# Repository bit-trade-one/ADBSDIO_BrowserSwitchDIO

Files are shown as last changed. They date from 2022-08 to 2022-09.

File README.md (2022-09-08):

# ADBSDIO/ADBSDIOMB_BrowserSwitchDIO
## 本体画像
<br>
<br>

WEBブラウザから接点監視・制御が可能なブラウザスイッチDIOのリポジトリです。

## [HPリンク](https://bit-trade-one.co.jp/adbsdio/) 

## [サポートサイト](https://bit-trade-one.github.io/ADBSDIO_BrowserSwitchDIO/)

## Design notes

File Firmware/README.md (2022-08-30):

# filelist
- Browser_Switch_DIO_Ver.XX.ino  
ファームウェア(Arduinoスケッチ)です。  
  
- Browser_Switch_DIO_Ver.XX.ino.leonardo.hex  
hexファイルです。 こちらはUSBVID・PIDが弊社で割り当てたものになっています。

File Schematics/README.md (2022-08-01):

# filelist
- ADBSDIO_PCBV0.pdf  
ADBSDIOの基板図です。
  
- ADBSDIO_SchematicV0.pdf  
ADBSDIOの回路図です。

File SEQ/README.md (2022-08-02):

※GitHubの使い方は[こちら](https://bit-trade-one.co.jp/h2gh/)の記事をご確認ください。
# filelist

- ADBSDIO_SEQ.pdf  
ADBSDIOの展開接続図のPDF版です。  
  
- ADBSDIO_SEQ.zip  
ADBSDIOの展開接続図のdxf版です。  
解凍してご利用ください。  
  
- 改造例SEQ.pdf  
既設盤と上記の配布SEQを組み合わせた展開接続図改造のサンプルです。

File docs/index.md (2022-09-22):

BTO-logo (https://bit-trade-one.co.jp/)

<a href="https://twitter.com/share?ref_src=twsrc%5Etfw" class="twitter-share-button" data-hashtags="Arduino,ブラウザスイッチDIO,BitTradeOne,ビット・トレード・ワン" data-url="https://bit-trade-one.github.io/ADBSDIO_BrowserSwitchDIO/" data-via="BitTradeOne" data-text="ブラウザスイッチDIOサポート" data-show-count="false">Tweetする</a>
<script async src="https://platform.twitter.com/widgets.js" charset="utf-8"></script>
       
# 出荷時設定
[IPaddress：192.168.1.10](http://192.168.1.10/)  
IPAddress subnet：255.255.255.0  
IPAddress gateway：192.168.1.1  
IPAddress dnsServer：192.168.1.1  

MACaddress：本体基板にシールで添付  
(汎用ターミナルソフトからも確認可能)  

コチラは変更可能です。  
下記のドキュメント項をご確認ください。  
  
ADBSDIOとADBSDIOMBの基板は同一のものです。  
# リンク
[製品HP](https://bit-trade-one.co.jp/adbsdio/)
# ドキュメント
<details><summary><strong>ADBSDIO概要</strong> </summary>
ADBSDIOと同ネットワークの端末WEBブラウザからリレー接点のON・OFFと接点がHIGHかLOWかの監視が可能です。<br>
またターミナル経由等でMACAddressと接続に使うIPAddress等の変更が可能です。<br>
入出力接点は全点絶縁されています。<br>
入出力接点端子はM3のネジ端子とピンソケットを用意しています。お好きな方をご利用ください。<br>
</details><br>
       
<details><summary><strong>簡易使用方法</strong> </summary>
1.ADBSDIOにUSBかネジ端子から電力を供給します。ネジ端子は8~26Vの電源の入力が可能です。+-に注意して接続してください。<br><br>
2.LANケーブルを接続しADBSDIOをネットワークに接続してください。<br>
制御端末もADBSDIOと同じネットワークに接続してください。<br><br>
<br>
<a href="https://user-images.githubusercontent.com/85532743/185073396-862e1109-ad1b-4813-9fc3-05c2a0810da8.png">クリックで拡大</a><br><br>
       
3.端末のブラウザから<a href="http://192.168.1.10/">http://192.168.1.10/</a>  に接続します。ここから監視・制御が可能です。<br>
 <br>
4.ネジ端子、ピンソケットに入力するもの、制御するものを接続ください。<br>
ネジ端子とピンソケットは赤枠で囲んだ部分が導通しています。<br>
<br><br>
<a href="https://user-images.githubusercontent.com/85532743/185340369-3af2de3d-b216-49eb-99b5-b47f519a5fbc.png">クリックで拡大</a><br><br>
<br>
<a href="https://user-images.githubusercontent.com/85532743/185077119-d89ff999-6a3d-499f-8601-80c3894757f6.png">クリックで拡大</a><br><br>
電圧入力はINの側が入力OUTの側が出力になるように接続ください。<br>
ブラウザスイッチは絶縁入力のため、入力部を駆動できる電圧が必要です。<br>
ブラウザスイッチ本体の5V出力を使うか、外部に電源を持たせて信号入力を行ってください。(DCIN 5~24V)<br>
無電圧接点出力(リレー接点出力)はCOMのC接点,NOのA接点,NCのB接点に気をつけて接続ください。(AC125V/3A, DC30V/3A)<br>
※ノイズの大きな機器をリレー接点に接続する場合は対策を行ってください。本体の動作に影響が出る可能性があります。<br>
また、比較的高い電圧を使う場合は細心の注意をはらってご使用ください。<br>
ADBSDIOのネジ端子に対応する裸端子は丸形 ニチフR0.75-3.5などです。<br>
</details><br>

<details><summary><strong>URLパラメータでの制御方法</strong> </summary>
ブラウザスイッチではURLのパラメータを確認して出力を制御しているため、以下のURLを送ることでも制御可能です。<br><br>
DO0のON<br>
http://192.168.1.10/?DO0=ON<br>
DO0のOFF<br>
http://192.168.1.10/?DO0=OFF<br>
DO1のON<br>
http://192.168.1.10/?DO1=ON<br>
DO1のOFF<br>
http://192.168.1.10/?DO1=OFF<br>
       
尚、IPアドレスを変更した場合は適宜読み替えてください。<br><br>

</details><br>

<details><summary><strong>MACAddress書き換え方法</strong> </summary>
1.ADBSDIOと設定するPCをUSBケーブルで接続してください。<br><br>
2.PC画面左下Windowsマークを右クリックし、デバイスマネージャを選び、ADBSDIOのCOMポート番号を確認してください。<br>
<br><br>
3.PCでTeraTermなどターミナルソフトを開き、COMポートを選択します。<br>
<br><br>
4.TeraTermの場合上のメニューから設定>端末を選び、送信の改行はLFを設定してください。<br>
<br>
<br><br>
5.なにかボタンを押すとセッティングモードに入ります。<br>
セッティングモードに入ったら「1」と「Enter」を入力してください。<br>
 注意:入力された文字はEnterを押すまでPC画面に反映されません。<br>
<br><br>
6.NEW_MAC_Address？と聞いてくるので新しいMACAddressを英数字のみで入力してください。<br>
大文字小文字は関係なく大文字に変換されます。<br>
入力に失敗しエラーが出た場合は5秒待ち、キーを入力し設定モードに入るところからやり直してください。<br>
設定ができたらUSBケーブルを抜き差しするかリセットボタンを押して再起動してください。MACAddressが適応されます。<br>
<br>
</details><br>

<details><summary><strong>MACAddress以外書き換え方法</strong> </summary>
1.ADBSDIOと設定するPCをUSBケーブルで接続してください。<br><br>
2.PC画面左下Windowsマークを右クリックし、デバイスマネージャを選び、ADBSDIOのCOMポート番号を確認してください。<br>
<br><br>
3.PCでTeraTermなどターミナルソフトを開き、COMポートを選択します。<br>
<br><br>
4.TeraTermの場合上のメニューから設定>端末を選び、送信の改行はLFを設定してください。<br>
<br>
<br><br>
5.なにかボタンを押すとセッティングモードに入ります。<br>
セッティングモードに入ったら「設定したい数字」と「Enter」を入力してください。<br>
今回は例としてIPAddressを設定します。「2」と「Enter」を入力してください。<br>
注意:入力された文字はEnterを押すまでPC画面に反映されません。<br>    
<br><br>
6.NEW_IP_Address？と聞いてくるので新しいIPAddressを数字のみで入力してください。<br>
入力に失敗しエラーが出た場合は5秒待ち、キーを入力し設定モードに入るところからやり直してください。<br>
設定ができたらUSBケーブルを抜き差しするかリセットボタンを押して再起動してください。MACAddressが適応されます。<br>
<br>

</details><br>

<details><summary><strong>ランド説明</strong> </summary>
ADBSDIOにはユーザがパターンカットやハンダブリッジをして設定ができるパッドが4つあります。<br>
恐れ入りますがハンダブリッジ・パターンカットをした場合保証は外れます。<br>
<br>
<a href="https://user-images.githubusercontent.com/85532743/182118702-53898fa7-c564-4b55-8915-5920560c63e0.png">クリックで拡大</a><br><br>

パターンカットはランドが露出していない部分をカッターナイフで2ラインほど切ると良いです。<br>
オープンしているパターンはランドをハンダブリッジで接続すると回路が閉じます。<br>
<br>

1.DI入力かAI入力か<br>
デフォルトでは絶縁のDI入力が選ばれていますが、パターンカットしてAIをハンダブリッジすることにより<br>
非絶縁AI入力が可能になります。なお、お客様の方でファームウェアを修正・書き直していただく必要があります。<br>
詳しくは回路図・ファームウェアをご確認ください。<br><br>

2.カットでブリーダ抵抗無効<br>
パターンをカットすることにより、ブリーダ抵抗が無効になり、入力側に流れる電流が減ります。<br>
詳しくは回路図をご確認ください。<br>
ブリーダ抵抗が無効の場合<br>
DC5Vを入力すると5mA，DC24Vを入力すると24mA電流が流れます。<br>
ブリーダ抵抗とは電流を多く流すために回路に並列に接続された抵抗です。<br>
接続する機器の接点定格の最小適用負荷に応じて、流れる電流を調整するために挿入されます。<br>
ブリーダ抵抗が有効の場合<br>
DC5Vを入力すると12.5mA，DC24Vを入力すると60mA電流が流れます。<br>
<br>
接続する接点に合わせて設定ください。<br><br>
<br>
<a href="https://user-images.githubusercontent.com/85532743/185068188-b91116f9-3ff9-4cda-ad21-cb990ff6aed6.png">クリックで拡大</a><br><br>
<br>
機器の接点が劣化し酸化膜が生成され小信号が伝達できなくなることを防ぐために<br>
接点部にメッキなどを施した製品は微小負荷接点対策品などと呼ばれます。<br>
<br>
接点に施しが無い、微小負荷接点対策がされていない機器は要求する最小負荷が大きく、<br>
接点に対してある程度大きな電流を流す必要があります。<br>
<br>
例えば富士電機製スーパータイマ MS4Sシリーズは、<br>
接点の最小適用負荷が DC5V10mAとなっています。<br>
この接点にはDC5V10mA以上の電圧・電流を流さないと、タイマ接点に発生する酸化皮膜などの絶縁が破壊できず、<br>
タイマ接点を閉じても電気信号が伝わらない可能性があります。<br>
<br>
ブリーダ抵抗を有効にすると、5Vの電源の場合約12mAを流すことが出来るので、<br>
タイマ接点からの信号を問題なく受け取ることが出来ます。  <br>
<br><br>
3.ブリッジでVIN端子有効<br>
ここをハンダブリッジすると、VIN端子より電源供給が可能になります。
詳しくは回路図をご確認ください。<br><br>
       
4.W5500設定<br>
ここをハンダブリッジすると、W5500の設定を変更することが出来ます。
詳しくは回路図・Wiznet社W5500のHPをご確認ください。<br><br>
</details><br>

<details><summary><strong>ファームウェア書き込み方法</strong> </summary>
       
ファームウェアはハードウェアの中に書き込まれているソフトウェアです。<br>
不具合修正や機能追加された新しいファームウェアが公開された際、<br>
ファームウェアをアップデートすることで新しい機能が使用できます。<br>
       
ADBSDIOはArduinoLeonardo互換のため、ArduinoIDEよりArduinoLeonardoを選択肢してUSBケーブル経由で<br>
ファームウェアを書き込む事ができます。<br>
なお、ArduinoIDEより書き込んだ場合ビット・トレード・ワンで付与したUSBVID・PIDではなくなります。<br>
通常使用では問題ありませんが、ADBSDIOを別の製品として再販売する場合はArduino社・弊社のUSBVID・PIDで販売することは<br>
推奨されていませんのでご注意ください。<br>
</details><br>

<details><summary><strong>DINレールについて</strong> </summary>
       
ケース付きのADBSDIOはDINレールに取り付けることが可能です。<br>
取り外しの際は白いレバーを引きながら取り外してください。<br>
</details><br>
  
# サポートファイル等
- [回路図・基板図](https://github.com/bit-trade-one/ADBSDIO_BrowserSwitchDIO/tree/master/Schematics)
- [配布展開接続図・改造例展開接続図サンプル](https://github.com/bit-trade-one/ADBSDIO_BrowserSwitchDIO/tree/master/SEQ)
- [ファームウェア・HEX](https://github.com/bit-trade-one/ADBSDIO_BrowserSwitchDIO/tree/master/Firmware) 
- [Q&A](FAQ.md)

# スペシャルサンクス
参考にさせていただきました。  
心より感謝いたします。誠にありがとうございました。

- [W5500](https://www.wiznet.io/product-item/w5500/)
- [Ethernet Library for Arduino](https://github.com/arduino-libraries/Ethernet)  
- Starting Electronics [Analog Inputs and Switches using AJAX](https://startingelectronics.org/tutorials/arduino/ethernet-shield-web-server-tutorial/AJAX-read-switches-analog/)  
- The Strange Storage [Arduino Ethernet シールド [改訂増分版]](https://www.storange.jp/2014/04/arduino-ethernet.html)

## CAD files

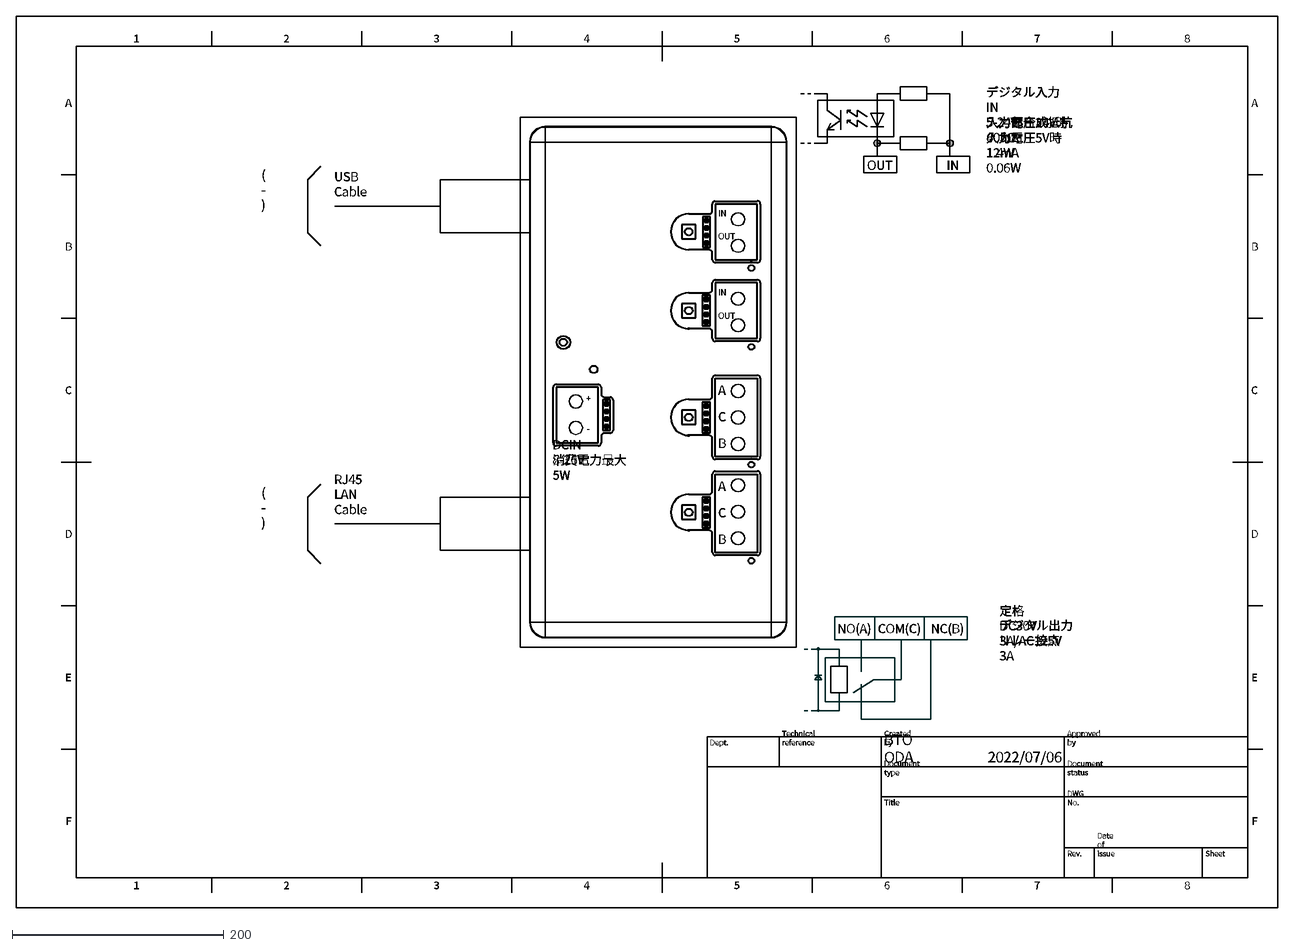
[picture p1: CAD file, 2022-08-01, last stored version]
SEQ/ADBSDIO_SEQ.dxf
1
A
2
3
4
5
6
7
8
B
C
D
E
F
Dept.
Technical reference
Created by
Approved by
Document type
Document status
Title
DWG No.
Rev.
Date of issue
Sheet
2022/07/06
BTO ODA
USB Cable
RJ45 LAN Cable
( - )
デジタル入力 IN 5-24V
入力部合成抵抗 405Ω
入力電圧24V時 60mA 1.4W
入力電圧5V時 12mA 0.06W
OUT
IN
デジタル出力
リレー接点
定格 DC30V 3A/AC125V 3A
NO(A)
COM(C)
NC(B)
DCIN 8-26V
消費電力最大 5W
+
-

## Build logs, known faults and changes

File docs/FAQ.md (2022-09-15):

# ADBSDIO_BrowserSwitchDIO よくある質問

---
## Q.入力部と制御回路は絶縁されていますか？

### A.はい 絶縁されています
絶縁耐圧等の公開はしておりません。

---

## Q.インジケータランプ・テスト用接点スイッチは入力部と絶縁されていますか。

### A.はい 絶縁されています

詳しくは[回路図](https://github.com/bit-trade-one/ADBSDIO_BrowserSwitchDIO/blob/master/Schematics/ADBSDIO_SchematicV0.pdf)をご確認ください。  

---

## Q.赤いランプが点滅して設定サイトにつなげません。故障ですか？

### A.MACアドレスが書き込まれていないという意です

何らかの原因でMACアドレスが保存されていない可能性がございます。  
サポートサイトを参考にMACアドレスを設定ください。  

---

## Q.設定サイトに繋がりません

### A.下記をご確認ください

- 本体に電源は刺さっているか
- LANケーブルは刺さっているか
- ネットワークに接続されているか
- 設定サイトにつなぐ端末が本体と同じネットワークに居るか  

上記で解消されない場合、別のIPアドレスにすると直ることがあります。 
(同じIPAddressを使用した機器がネットワーク内にいる場合に発生します。)  
サポートトップドキュメントのIPAddress書き換え方法をご覧ください。  
  
それでも解消されない際は[お問い合わせ](https://bit-trade-one.co.jp/contactus/)ください。  

---

## Q.設定サイトには同時に何台まで接続できますか？

### A.2,3台接続できることは確認しています。

弊社環境での確認です。

それぞれの端末が非同期で値を確認するため、常時多数接続には向いていないかもしれません。

---

## Q.DHCPに対応していますか？

### A.非対応です。

発売時FWでは対応していませんが、  
W5500を採用しているため、FWをお客様の方で作成していただければDHCP対応は可能です。

しかし本体メモリの消費が大きいため実装時はご注意ください。

---

## Q.IPv6に対応していますか？

### A.非対応です

W5500を採用しているため、IPv4にのみ対応しています。  

---
## Q.電源を消した場合DO出力のHIGH・LOWは保持されますか？

### A.保持されません

DO出力のHIGH・LOWは揮発メモリ上で管理されているため、電源を抜くと初期値の双方LOWに戻ります。  
電源が不安定な状況などでのご使用にはご注意ください。  

---

## Q.USB電源とねじ端子からの電源を双方つなぎ、電源の二重化をすることは可能ですか？

### A.そのような使い方は想定しておりません。

逆流防止ダイオードが実装されているので双方繋いでも故障等は発生しませんが、  
電源の二重化として使用する事は想定しておりません。  

---

## Q.確認用LEDが光っているけど信号入力されません

### A.入力電圧が低い可能性がございます。

LEDの特性により、入力に値しない低めの電圧が入力されたときでも確認用LEDが光ることがございます。  
5V以上の信号を入力ください。

---

## Q.ブラウザではなくコマンドラインから制御することは可能ですか？

### A.あくまで簡易的ですが、可能です。

wgetコマンドを使用することによりDO出力のON・OFFを行うことができます。  
連続実行した場合は、直前のコマンドが無視されるなど不安定な挙動をすることがあります。  
また、タイムアウトとトライ回数については、用途に応じて調整する必要があります。  

Linuxの場合  
```
wget -T 5 -t 1 -O /dev/null http://192.168.1.32/DO0=ON  2> /dev/null #DO0 ON
wget -T 5 -t 1 -O /dev/null http://192.168.1.32/DO0=OFF 2> /dev/null #DO0 OFF
wget -T 5 -t 1 -O /dev/null http://192.168.1.32/DO1=ON  2> /dev/null #DO1 ON
wget -T 5 -t 1 -O /dev/null http://192.168.1.32/DO1=OFF 2> /dev/null #DO1 OFF
```
 
Windowsの場合（wgetコマンドは別途インストールする必要があります）  
```
wget -T 5 -t 1 -O nul http://192.168.1.32/DO0=ON  2> nul ; DO0 ON
wget -T 5 -t 1 -O nul http://192.168.1.32/DO0=OFF 2> nul ; DO0 OFF
wget -T 5 -t 1 -O nul http://192.168.1.32/DO1=ON  2> nul ; DO1 ON
wget -T 5 -t 1 -O nul http://192.168.1.32/DO1=OFF 2> nul ; DO1 OFF
```

---

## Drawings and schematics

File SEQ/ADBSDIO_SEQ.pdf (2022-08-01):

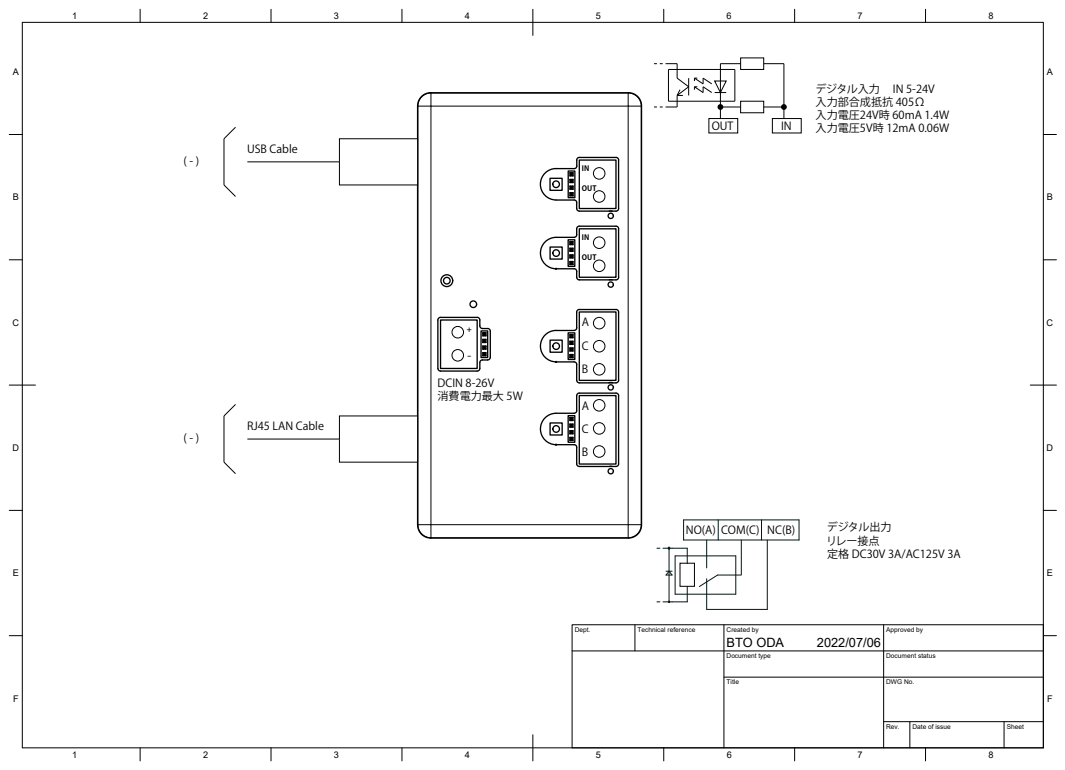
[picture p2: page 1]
Dept.; Technical reference; Created by; Approved by; Document type; Document status; Title; DWG No.; Rev.; Date of issue; Sheet; BTO ODA; USB Cable; RJ45 LAN Cable; デジタル入力 IN 5-24V 入力部合成抵抗 405Ω 入力電圧24V時 60mA 1.4W; OUT; 入力電圧5V時 12mA 0.06W; デジタル出力 リレー接点 定格 DC30V 3A/AC125V 3A; NO(A) COM(C); DCIN 8-26V 消費電力最大 5W

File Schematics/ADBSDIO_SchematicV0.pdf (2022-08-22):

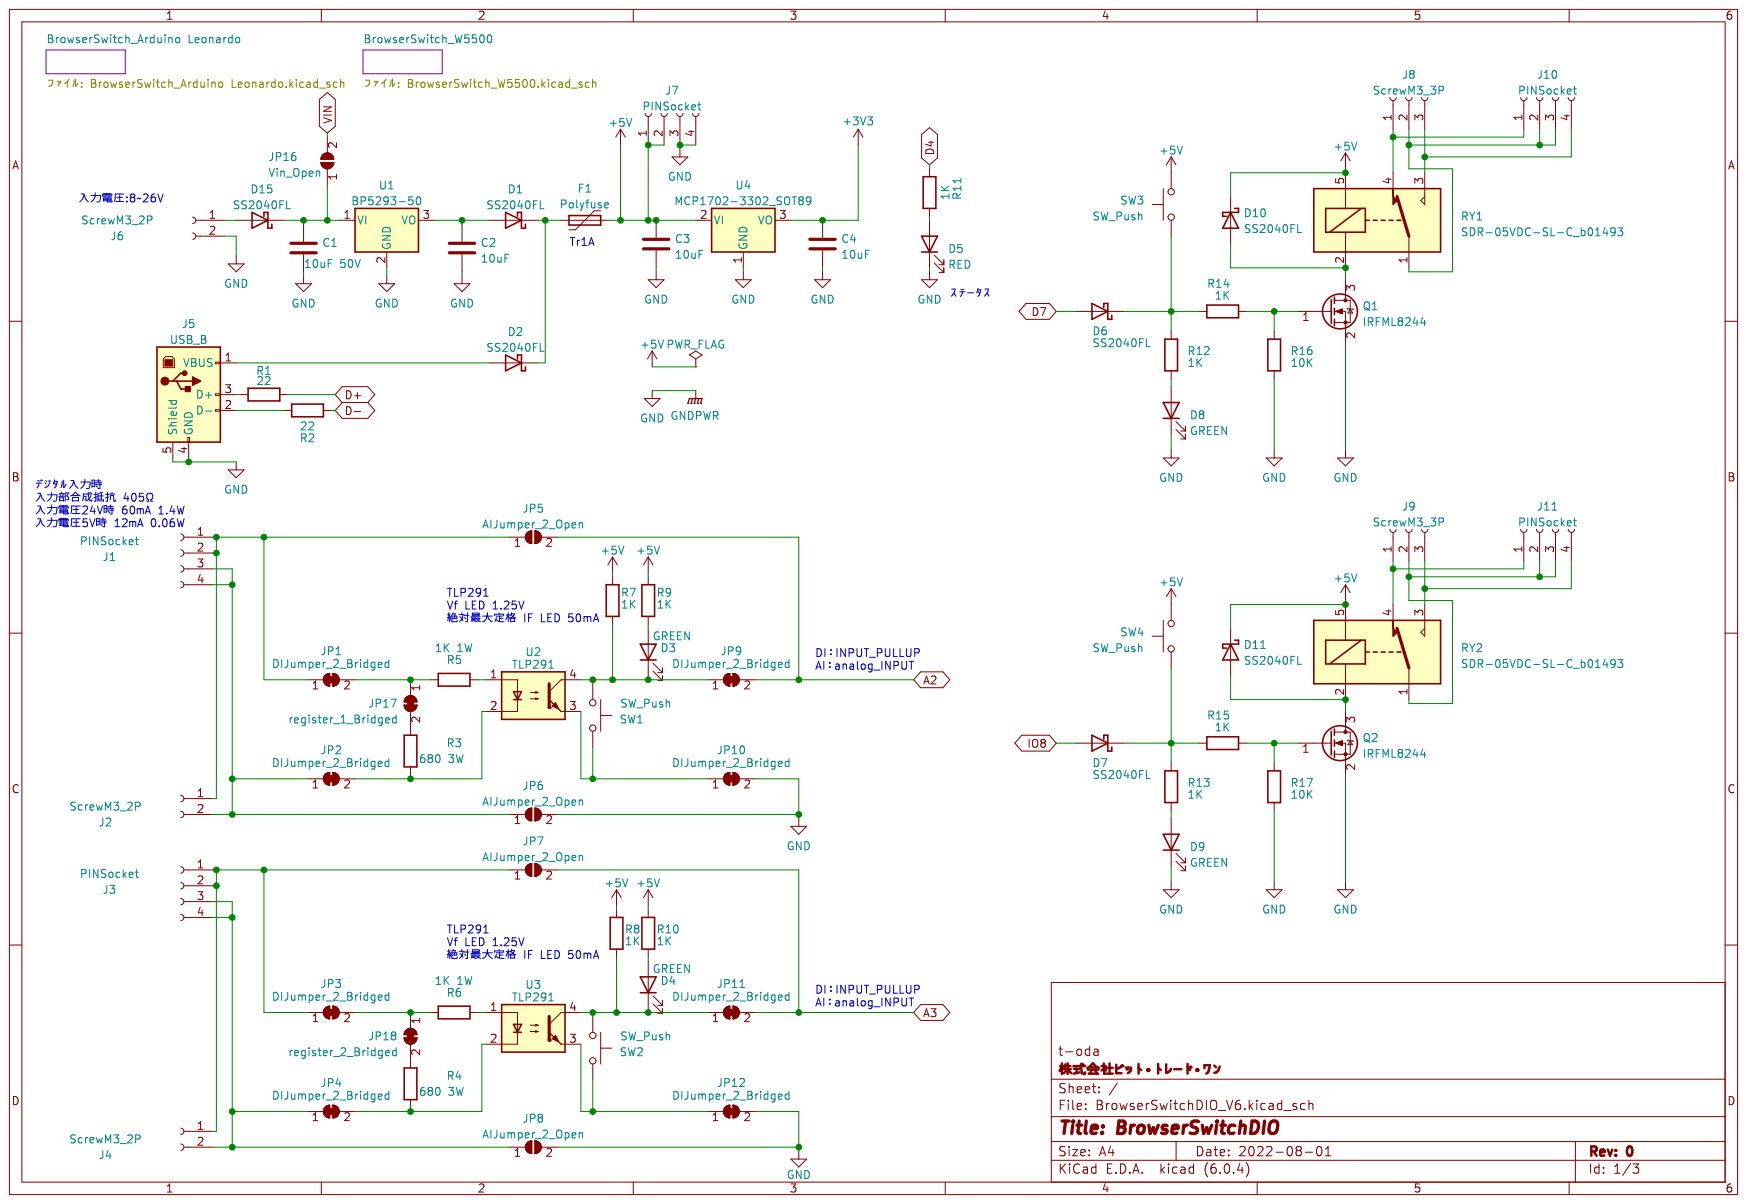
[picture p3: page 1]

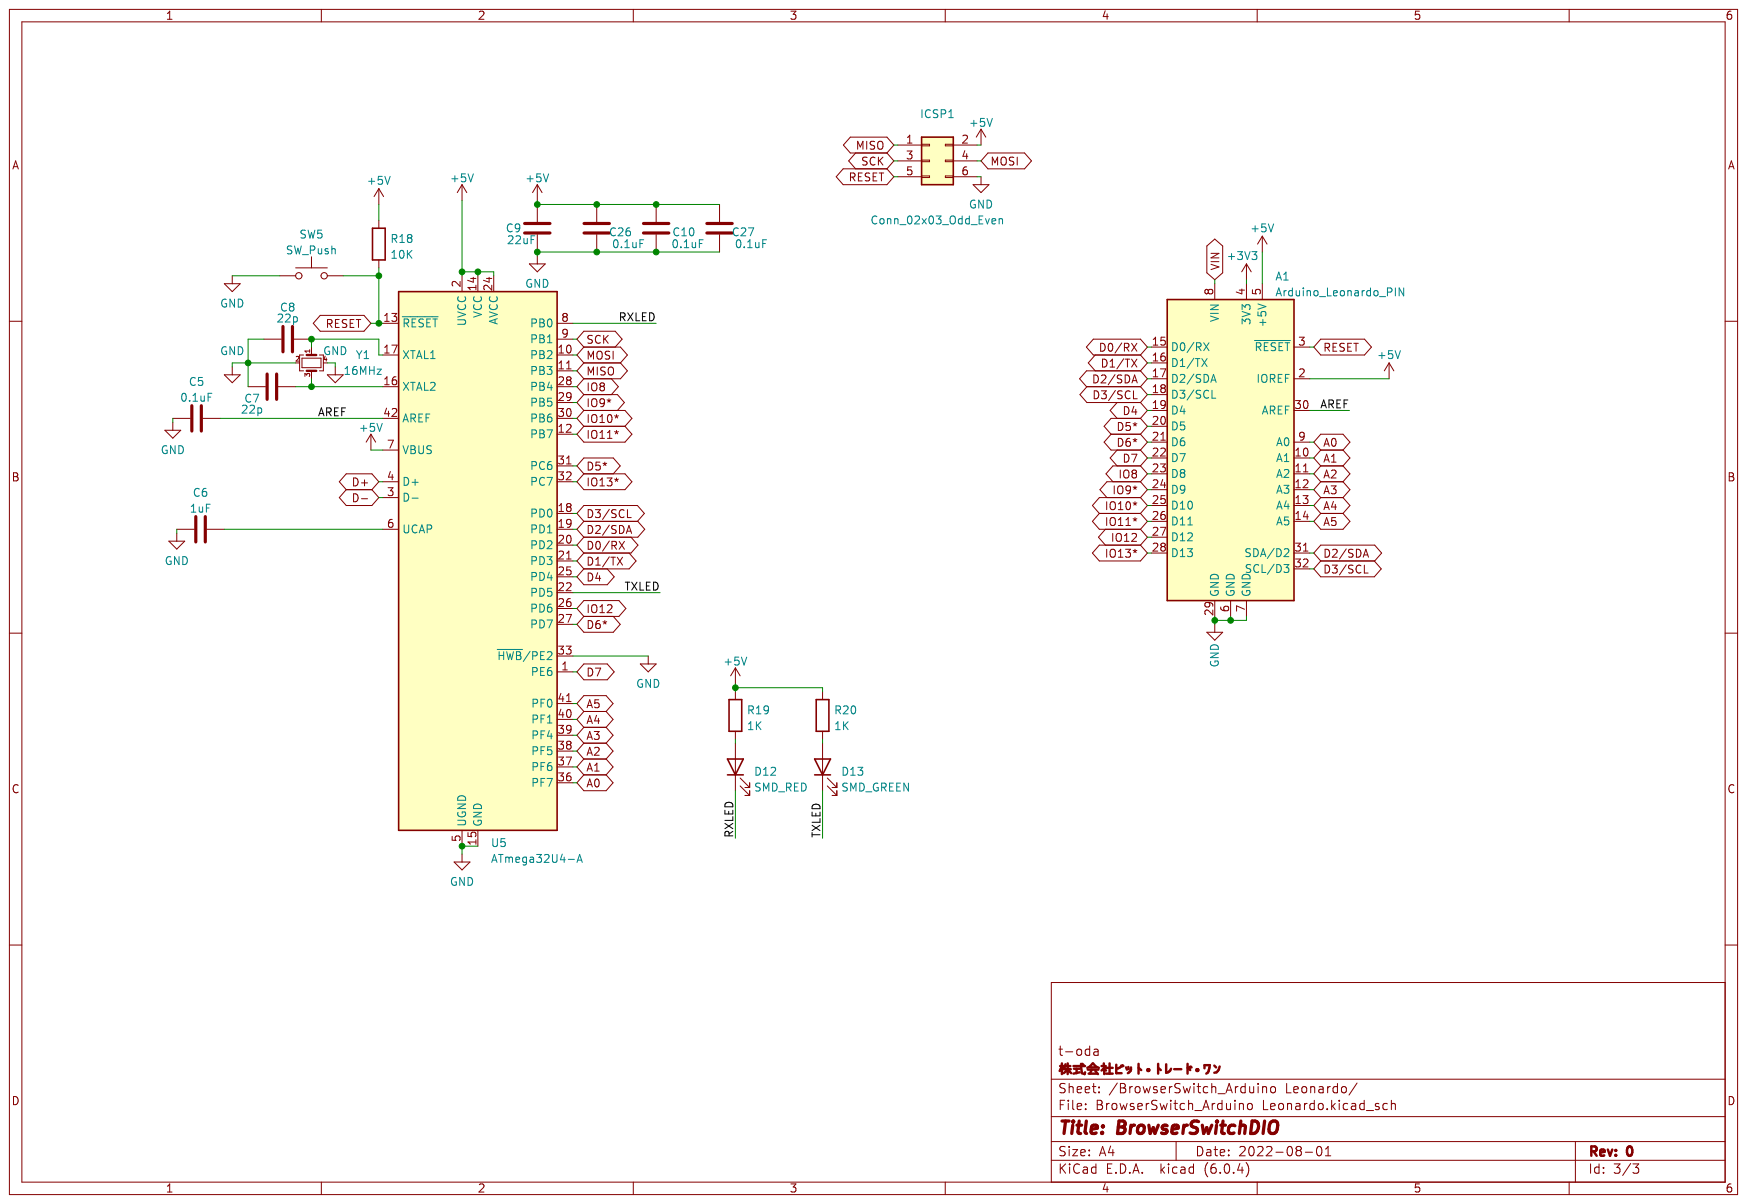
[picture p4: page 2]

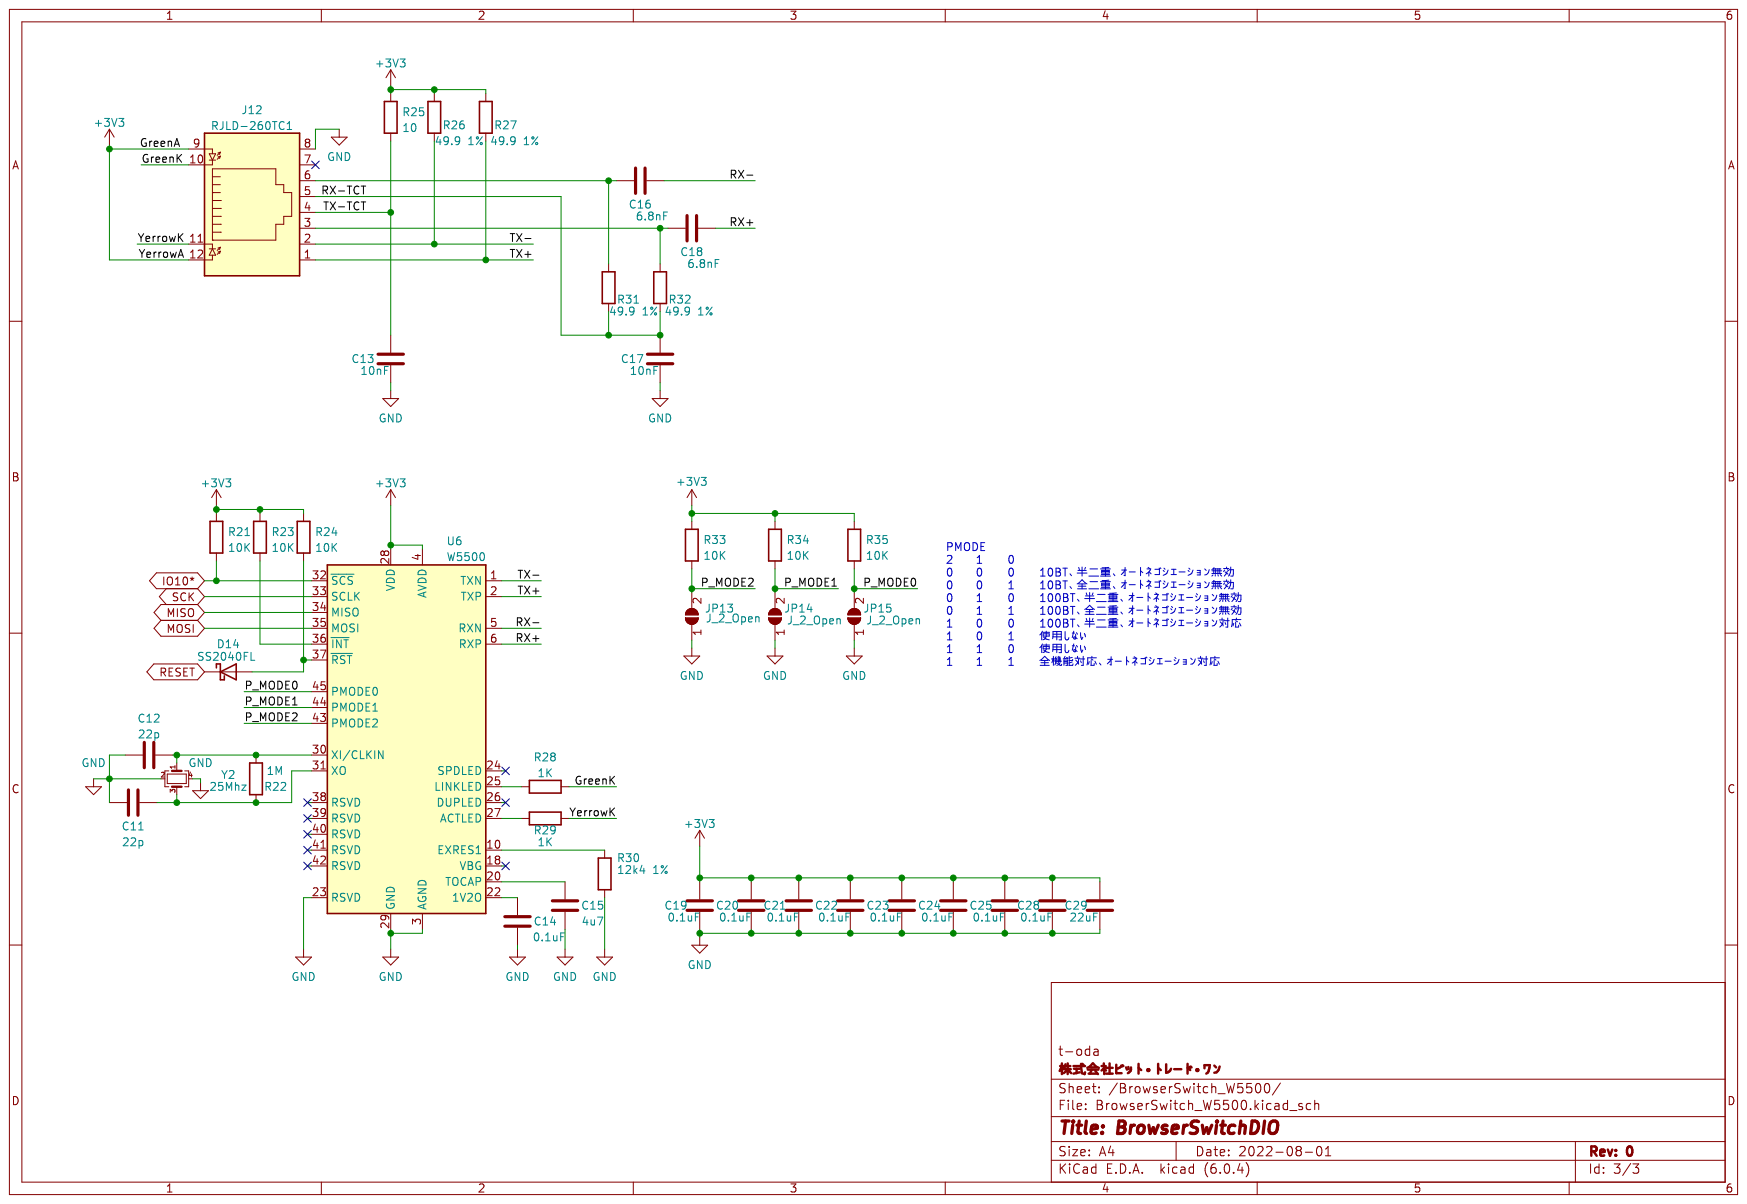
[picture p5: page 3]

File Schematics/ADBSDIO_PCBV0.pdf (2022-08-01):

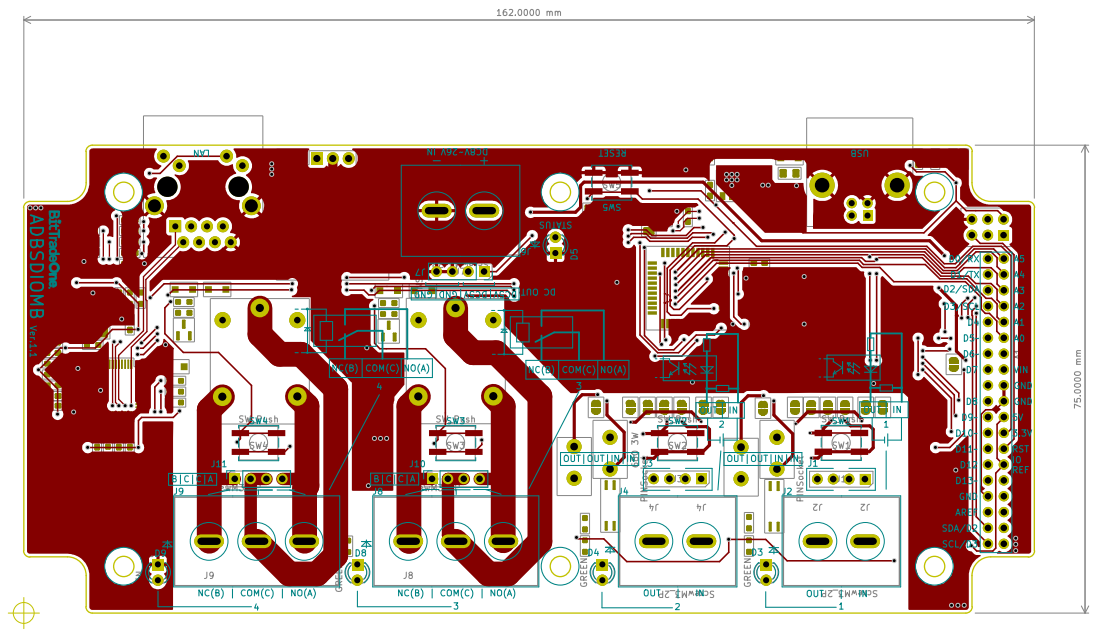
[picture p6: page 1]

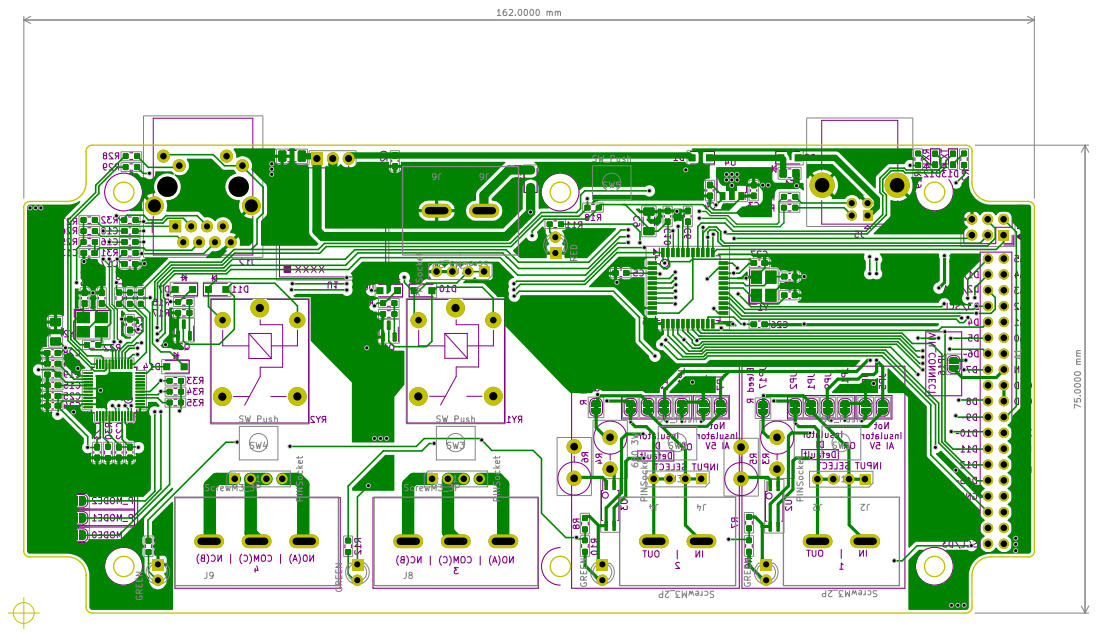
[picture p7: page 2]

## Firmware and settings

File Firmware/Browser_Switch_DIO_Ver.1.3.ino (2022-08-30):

//bto_ODA_220830Ver.1.3
//発売時のVendorID:0x22EA
//発売時のProductID:0x0078

#include <SPI.h>
#include <Ethernet2.h>//Ver.1.0.4
#include <EEPROM.h>

byte mac[] = {EEPROM[0x00], EEPROM[0x01], EEPROM[0x02], EEPROM[0x03], EEPROM[0x04], EEPROM[0x05]};
byte ip[] = {EEPROM[0x06], EEPROM[0x07], EEPROM[0x08], EEPROM[0x09]};

IPAddress subnet{EEPROM[0x0A], EEPROM[0x0B], EEPROM[0x0C], EEPROM[0x0D]};
IPAddress gateway{EEPROM[0x0E], EEPROM[0x0F], EEPROM[0x10], EEPROM[0x11]};
IPAddress dnsServer{EEPROM[0x12], EEPROM[0x13], EEPROM[0x14], EEPROM[0x15]};

EthernetServer server(80); // ポート80(HTTP)で通信をするサーバを初期化

String HTTP_req;           //HTTPリクエストを保存
boolean DO0_status = 0;
boolean DO1_status = 0;
boolean DO2_status = 0;
boolean DO3_status = 0;

const int DI0 = A2;
const int DI1 = A3;

const int DO0 = 7;
const int DO1 = 8;

const int STATUS = 4;

void setup()
{
  Serial.setTimeout(20000);




  pinMode(DI0, INPUT);
  pinMode(DI1, INPUT);

  pinMode(DO0, OUTPUT);
  pinMode(DO1, OUTPUT);
  pinMode(STATUS, OUTPUT);
  digitalWrite(STATUS, HIGH);
  if (EEPROM[0x00] == 255 && EEPROM[0x01] == 255 && EEPROM[0x02] == 255 && EEPROM[0x03] == 255 && EEPROM[0x04] == 255 && EEPROM[0x05] == 255) { //EEPROMが初期値なら
    byte LEDtime = 0;
    while (true) { //無限ループ↓
      LEDtime++;
      delay(1);
      Serial_setting();
      if (LEDtime >  254 ) {
        Serial.println(F("MAC_address_Error"));
        digitalWrite(STATUS, !digitalRead(STATUS)); //パイロットランプ点滅
        LEDtime = 0;
      }//無限ループ↑
    }
  }

  Ethernet.begin(mac, ip, dnsServer, gateway, subnet);
  server.begin();
  Serial.begin(9600);
}

void loop()
{

  EthernetClient client = server.available();  //クライアントを取得

  if (client) {  //クライアントを取得したか？
    boolean currentLineIsBlank = true;
    while (client.connected()) {
      if (client.available()) {
        char c = client.read(); //クライアントから1バイト（文字）を読み取ります
        HTTP_req += c;  //HTTPリクエストを一度に1文字保存します
        //クライアントリクエストの最後の行は空白で、\nで終わります
        if (c == '\n' && currentLineIsBlank) {//最後の行を受信した後にのみクライアントに応答します

          //標準のhttp応答ヘッダーを送信
          client.println("HTTP/1.1 200 OK");
          client.println("Content-Type: text/html");
          client.println("Connection: keep-alive");
          client.println();
          //スイッチ状態のAJAXリクエスト
          if (HTTP_req.indexOf("ajax_switch") > -1) {
            //スイッチの状態を読み取る
            GetAjaxData(client);
          }
          else {  //WebページのHTTPリクエスト
            //Webページを送信-AJAX呼び出しを含むJavaScriptが含まれてる
            client.println(F("<!DOCTYPE html>"));
            client.println(F("<html>"));
            client.println(F("<head>"));
            client.println(F("<meta name=viewport content=width=device-width>"));
            client.println(F("<title>Browser Switch DIO</title>"));
            client.println(F("<script>"));
            client.println(F("function GetSwitchData() {"));

            //client.println(F(""));
            client.println(F("var url = new URL(window.location.href);"));//GET部をブラウザURLから削除
            client.println(F("var params = url.searchParams;"));
            client.println(F("params.delete('mode');"));
            client.println(F("history.replaceState('', '', url.pathname);"));

            client.println(F("nocache = \"&nocache=\" + Math.random() * 1000000;"));
            client.println(F("var request = new XMLHttpRequest();"));
            client.println(F("request.onreadystatechange = function() {"));
            client.println(F("if (this.readyState == 4) {"));
            client.println(F("if (this.status == 200) {"));
            client.println(F("if (this.responseText != null) {"));
            client.println(F("document.getElementById(\"sw_data\")\.innerHTML = this.responseText;"));
            client.println(F("}}}}"));
            client.println(F("request.open(\"GET\", \"ajax_switch\" + nocache, true);"));
            client.println(F("request.send(null);"));
            client.println(F("setTimeout('GetSwitchData()', 3000);"));
            client.println(F("}"));
            client.println(F("</script>"));
            client.println(F("</head>"));
            client.println(F("<div style='padding: 30px 40px 50px 40px; '>"));
            client.println(F("<body style='color:rgb(0,0,0);text-align:left;'>"));
            client.println(F("<body onload=\"GetSwitchData()\">"));
            client.println(F("<p><font size='6' color='#4169E1'><b>Browser Switch DIO</b></font></p>"));

            client.println(F("<p><font size='2' color='#808080'>refresh/3s<br /></font><p>"));
            client.println(F("<div id=\"sw_data\">"));
            client.println(F("</div>"));
            client.println(F("<footer>"));
            client.println(F("<hr>"));
            client.println(F("<p style=text-align:center;><font size='2' color='#808080'>bit-trade-one.LTD<br /></font></p>"));
            client.println(F("</footer>"));
            client.println(F("</body>"));
            client.println(F("</html>"));

          }

          if (HTTP_req.indexOf("DO0=ON") > -1 ) {
            DO0_status = 1;

          } else if (HTTP_req.indexOf("DO0=OFF") > -1 ) {
            DO0_status = 0;

          }  else if (HTTP_req.indexOf("DO1=ON") > -1 ) {
            DO1_status = 1;

          } else if (HTTP_req.indexOf("DO1=OFF") > -1 ) {
            DO1_status = 0;
          }

          //受信したHTTPリクエストをシリアルポートに表示
          Serial.print(HTTP_req);
          HTTP_req = "";            //リクエストで終了、空の文字列
          break;
        }
        //クライアントから受信したテキストのすべての行は\r\nで終わる
        if (c == '\n') {
          //受信したテキストの行の最後の文字
          //改行を開始
          currentLineIsBlank = true;
        }
        else if (c != '\r') {
          //クライアントからテキスト文字を受信
          currentLineIsBlank = false;
        }
      } // end if (client.available())
    } // end while (client.connected())
    delay(1);      //Webブラウザにデータを受信する時間を与える
    client.stop(); //接続閉じ
  } // end if (client)
  Serial_setting();//何か入力があればSettingモードへ
}

void GetAjaxData(EthernetClient cl)
{
  ///*---------------------------------------------
  cl.println(F("<form method=GET>"));

  if (digitalRead(DI0)) {
    cl.println(F("<p><b>1:DI0</b> : LOW</p>"));
  }
  else {
    cl.println(F("<p><b>1:DI0</b> : <font color=red><b>HIGH</b></font></p>"));
  }

  if (digitalRead(DI1)) {
    cl.println(F("<p><b>2:DI1</b> : LOW</p>"));
  }
  else {
    cl.println(F("<p><b>2:DI1</b> : <font color=red><b>HIGH</b></font></p>"));
  }
  //*/
  /*---------------------------------------------
    int analog_val_A0 = 0;
    int analog_val_A1 = 0;

    analog_val_A0 = analogRead(DI0);
    analog_val_A1 = analogRead(DI1);

    cl.print(F("<p><b>1:AI0</b> : "));
    cl.print(analog_val_A0);
    cl.println(F("</p>"));

    cl.print(F("<p><b>2:DI1</b> : "));
    cl.print(analog_val_A1);
    cl.println(F("</p>"));

  */

  cl.println(F("<hr>"));
  if (DO0_status == 1) {  // see if checkbox was clicked
    digitalWrite(DO0, HIGH);
    cl.print(F("<p><b>3:DO0</b> : <label for=DO0_ON><input type=radio id=DO0_ON name=DO0 value=ON  checked=checked onclick= submit()>ON</label>"));
    cl.print(F("<label for=DO0_OFF><input type=radio id=DO0_OFF name=DO0 value=OFF onclick= submit()>OFF</label></p>"));
  } else if (DO0_status == 0) {
    digitalWrite(DO0, LOW);
    cl.print(F("<p><b>3:DO0</b> : <label for=DO0_ON><input type=radio id=DO0_ON name=DO0 value=ON   onclick= submit()>ON</label>"));
    cl.print(F("<label for=DO0_OFF><input type=radio id=DO0_OFF name=DO0 value=OFF checked=checked onclick= submit()>OFF</label></p>"));
  }
  cl.println(F("</form>"));
  cl.println(F("<form method=GET>"));
  if (DO1_status == 1) {  // see if checkbox was clicked
    digitalWrite(DO1, HIGH);
    cl.print(F("<p><b>4:DO1</b> : <label for=DO1_ON><input type=radio id=DO1_ON name=DO1 value=ON  checked=checked onclick= submit()>ON</label>"));
    cl.print(F("<label for=DO1_OFF><input type=radio id=DO1_OFF name=DO1 value=OFF onclick= submit()>OFF</label></p>"));
  } else if (DO1_status == 0) {
    digitalWrite(DO1, LOW);
    cl.print(F("<p><b>4:DO1</b> : <label for=DO1_ON><input type=radio id=DO1_ON name=DO1 value=ON   onclick= submit()>ON</label>"));
    cl.print(F("<label for=DO1_OFF><input type=radio id=DO1_OFF name=DO1 value=OFF checked=checked onclick= submit()>OFF</label></p>"));
  }
  cl.println(F("</form>"));
  cl.println(F("<form method=GET>"));

  cl.println(F("</form>"));
}

void Serial_setting() {
  if (Serial.read() != -1) {//何か入力があれば設定モードへ※本モード中WEBサーバは止まります。設定後は要再起動
    String scan_string;
    scan_string = Serial.read();
    scan_string = "";
    Serial.println();
    Serial.println(F("ADBSDIO Setting Mode!"));
    Serial.println(F("TIME OUT 20s_EOL:LF"));
    Serial.println(F("Ver.1.3"));
    Serial.println(F("Current address"));
    Serial.print(F("MAC_"));
    for (int i = 0; i < 6; i++) {
      if (EEPROM[i] <= 16 )Serial.print("0"); //表示用 16以下であれば0埋め
      Serial.print(EEPROM.read(i), HEX);
      if (i < 5)Serial.print(":");//区切り文字表示
    }
    Serial.println();
    Serial.print(F("IP_"));
    for (int i = 6; i < 10; i++) {
      Serial.print(EEPROM.read(i), DEC);
      if (i < 9)Serial.print(".");//区切り文字表示
    }
    Serial.println();
    Serial.print(F("subnet_"));
    for (int i = 10; i < 14; i++) {
      Serial.print(EEPROM.read(i), DEC);
      if (i < 13)Serial.print(".");//区切り文字表示
    }
    Serial.println();
    Serial.print(F("gateway_"));
    for (int i = 14; i < 18; i++) {
      Serial.print(EEPROM.read(i), DEC);
      if (i < 17)Serial.print(".");//区切り文字表示
    }
    Serial.println();
    Serial.print(F("dnsServer_"));
    for (int i = 18; i < 22; i++) {
      Serial.print(EEPROM.read(i), DEC);
      if (i < 21)Serial.print(".");//区切り文字表示
    }
    Serial.println();
    Serial.println(F("Num?"));
    Serial.println(F("1:MAC"));
    Serial.println(F("2:IP"));
    Serial.println(F("3:subnet"));
    Serial.println(F("4:gateway"));
    Serial.println(F("5:dnsServer"));
    Serial.println(F("X:Exit"));

    while (!Serial.available()); //入力があるまで待機
    scan_string = Serial.readStringUntil('\n');
    scan_string.trim();
    Serial.print(F(">>"));
    Serial.println(scan_string);

    //***選択肢1***MACアドレス書き換えモードへ(6バイトの配列)*/
    if (scan_string.equals("1")) {
      Serial.println(F("NEW_MAC_address?(Number Only_sample:8C1F646EC000)"));
      Serial.println(F(">>"));
      while (!Serial.available()); //入力があるまで待機
      scan_string = Serial.readStringUntil('\n');//入力内容の表示
      scan_string.trim();
      Serial.print(F(">>"));
      Serial.println(scan_string);

      if (scan_string.length() == 12) { //文字数がOKか
        Serial.println(F("update!"));

        //12文字のHEXを表している文字列を2文字ずつ結合しEEPROMへ格納
        String i_string;
        char char_buf[5];
        i_string = "0x";
        i_string += scan_string[0];
        i_string += scan_string[1];
        i_string.toCharArray(char_buf, 5);
        EEPROM[0x00] = strtol(char_buf, NULL, 16);

        i_string = "0x";
        i_string += scan_string[2];
        i_string += scan_string[3];
        i_string.toCharArray(char_buf, 5);
        EEPROM[0x01] = strtol(char_buf, NULL, 16);

        i_string = "0x";
        i_string += scan_string[4];
        i_string += scan_string[5];
        i_string.toCharArray(char_buf, 5);
        EEPROM[0x02] = strtol(char_buf, NULL, 16);

        i_string = "0x";
        i_string += scan_string[6];
        i_string += scan_string[7];
        i_string.toCharArray(char_buf, 5);
        EEPROM[0x03] = strtol(char_buf, NULL, 16);

        i_string = "0x";
        i_string += scan_string[8];
        i_string += scan_string[9];
        i_string.toCharArray(char_buf, 5);
        EEPROM[0x04] = strtol(char_buf, NULL, 16);

        i_string = "0x";
        i_string += scan_string[10];
        i_string += scan_string[11];
        i_string.toCharArray(char_buf, 5);
        EEPROM[0x05] = strtol(char_buf, NULL, 16);

        //EEPROMからMAC_addressを読む
        for (int i = 0; i < 6; i++) {
          if (EEPROM[i] <= 16 )Serial.print("0"); //16以下(1桁)であれば0埋め
          Serial.print(EEPROM.read(i), HEX);
          if (i < 5)Serial.print(":");//区切り文字表示
        }
        Serial.println();

      } else {                         //文字数が合わなければエラー
        Serial.println(F("length_Error!"));
      }

      //***選択肢2***ipアドレス書き換えモードへ(4バイトの配列)*/
    } else if (scan_string.equals("2")) {
      Serial.println(F("NEW_IP_address?(Number Only_sample:192168001010)"));
      Serial.println(F(">>"));
      while (!Serial.available()); //入力があるまで待機
      scan_string = Serial.readStringUntil('\n');//入力内容の表示
      scan_string.trim();
      Serial.print(F(">>"));
      Serial.println(scan_string);

      if (scan_string.length() == 12) { //文字数がOKか
        Serial.println(F("update!"));
        //12文字のIPを表している文字列を3文字ずつ結合しEEPROMへ格納
        String i_string;
        char char_buf[5];

        i_string = "";
        i_string += scan_string[0];
        i_string += scan_string[1];
        i_string += scan_string[2];
        EEPROM[0x06] = (byte)i_string.toInt();

        i_string = "";
        i_string += scan_string[3];
        i_string += scan_string[4];
        i_string += scan_string[5];
        EEPROM[0x07] = (byte)i_string.toInt();

        i_string = "";
        i_string += scan_string[6];
        i_string += scan_string[7];
        i_string += scan_string[8];
        EEPROM[0x08] = (byte)i_string.toInt();

        i_string = "";
        i_string += scan_string[9];
        i_string += scan_string[10];
        i_string += scan_string[11];
        EEPROM[0x09] = (byte) i_string.toInt();


        //EEPROMからip_addressを読む
        for (int i = 6; i < 10; i++) {
          Serial.print(EEPROM.read(i), DEC);
          if (i < 9)Serial.print(".");//区切り文字表示
        }
        Serial.println();
      } else {                         //文字数が合わなければエラー
        Serial.println(F("length_Error!"));
      }

      //***選択肢3***subnetアドレス書き換えモードへ(4バイトの配列)*/
    } else if (scan_string.equals("3")) {
      Serial.println(F("NEW_subnet?(Number Only_sample:192168001010)"));
      Serial.println(F(">>"));
      while (!Serial.available()); //入力があるまで待機
      scan_string = Serial.readStringUntil('\n');//入力内容の表示
      scan_string.trim();
      Serial.print(F(">>"));
      Serial.println(scan_string);

      if (scan_string.length() == 12) { //文字数がOKか
        Serial.println(F("update!"));
        //12文字のIPを表している文字列を3文字ずつ結合しEEPROMへ格納
        String i_string;
        char char_buf[5];

        i_string = "";
        i_string += scan_string[0];
        i_string += scan_string[1];
        i_string += scan_string[2];
        EEPROM[0x0A] = (byte)i_string.toInt();

        i_string = "";
        i_string += scan_string[3];
        i_string += scan_string[4];
        i_string += scan_string[5];
        EEPROM[0x0B] = (byte)i_string.toInt();

        i_string = "";
        i_string += scan_string[6];
        i_string += scan_string[7];
        i_string += scan_string[8];
        EEPROM[0x0C] = (byte)i_string.toInt();

        i_string = "";
        i_string += scan_string[9];
        i_string += scan_string[10];
        i_string += scan_string[11];
        EEPROM[0x0D] = (byte) i_string.toInt();


        //EEPROMから読む
        for (int i = 10; i < 14; i++) {
          Serial.print(EEPROM.read(i), DEC);
          if (i < 13)Serial.print(".");//区切り文字表示
        }
        Serial.println();
      } else {                         //文字数が合わなければエラー
        Serial.println(F("length_Error!"));
      }

      //***選択肢4***gatewayアドレス書き換えモードへ(4バイトの配列)*/
    } else if (scan_string.equals("4")) {
      Serial.println(F("NEW_gateway?(Number Only_sample:192168001010)"));
      Serial.println(F(">>"));
      while (!Serial.available()); //入力があるまで待機
      scan_string = Serial.readStringUntil('\n');//入力内容の表示
      scan_string.trim();
      Serial.print(F(">>"));
      Serial.println(scan_string);

      if (scan_string.length() == 12) { //文字数がOKか
        Serial.println(F("update!"));
        //12文字のIPを表している文字列を3文字ずつ結合しEEPROMへ格納
        String i_string;
        char char_buf[5];

        i_string = "";
        i_string += scan_string[0];
        i_string += scan_string[1];
        i_string += scan_string[2];
        EEPROM[0x0E] = (byte)i_string.toInt();

        i_string = "";
        i_string += scan_string[3];
        i_string += scan_string[4];
        i_string += scan_string[5];
        EEPROM[0x0F] = (byte)i_string.toInt();

        i_string = "";
        i_string += scan_string[6];
        i_string += scan_string[7];
        i_string += scan_string[8];
        EEPROM[0x10] = (byte)i_string.toInt();

        i_string = "";
        i_string += scan_string[9];
        i_string += scan_string[10];
        i_string += scan_string[11];
        EEPROM[0x11] = (byte) i_string.toInt();


        //EEPROMから読む
        for (int i = 14; i < 18; i++) {
          Serial.print(EEPROM.read(i), DEC);
          if (i < 17)Serial.print(".");//区切り文字表示
        }
        Serial.println();
      } else {                         //文字数が合わなければエラー
        Serial.println(F("length_Error!"));
      }

      //***選択肢5***dnsServerアドレス書き換えモードへ(4バイトの配列)*/
    } else if (scan_string.equals("5")) {
      Serial.println(F("NEW_dnsServer?(Number Only_sample:192168001010)"));
      Serial.println(F(">>"));
      while (!Serial.available()); //入力があるまで待機
      scan_string = Serial.readStringUntil('\n');//入力内容の表示
      scan_string.trim();
      Serial.print(F(">>"));
      Serial.println(scan_string);

      if (scan_string.length() == 12) { //文字数がOKか
        Serial.println(F("update!"));
        //12文字のIPを表している文字列を3文字ずつ結合しEEPROMへ格納
        String i_string;
        char char_buf[5];

        i_string = "";
        i_string += scan_string[0];
        i_string += scan_string[1];
        i_string += scan_string[2];
        EEPROM[0x12] = (byte)i_string.toInt();

        i_string = "";
        i_string += scan_string[3];
        i_string += scan_string[4];
        i_string += scan_string[5];
        EEPROM[0x13] = (byte)i_string.toInt();

        i_string = "";
        i_string += scan_string[6];
        i_string += scan_string[7];
        i_string += scan_string[8];
        EEPROM[0x14] = (byte)i_string.toInt();

        i_string = "";
        i_string += scan_string[9];
        i_string += scan_string[10];
        i_string += scan_string[11];
        EEPROM[0x15] = (byte) i_string.toInt();


        //EEPROMから読む
        for (int i = 18; i < 22; i++) {
          Serial.print(EEPROM.read(i), DEC);
          if (i < 21)Serial.print(".");//区切り文字表示
        }
        Serial.println();
      } else {                         //文字数が合わなければエラー
        Serial.println(F("length_Error!"));
      }
    } else {//***選択肢以外***抜ける
      Serial.println(F("Setting Mode Exit"));
    }
    Serial.println(F("Please reboot for the settings to take effect"));
    Serial.println(F("bye.Resume after 5 seconds"));
    Serial.println();
    delay(5000);

  }
}

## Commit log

2022-08-01 Update index.md
    ドキュメント追記
2022-09-14 Update FAQ.md
    ブラウザではなくコマンドラインから制御することは可能ですか？を追加
